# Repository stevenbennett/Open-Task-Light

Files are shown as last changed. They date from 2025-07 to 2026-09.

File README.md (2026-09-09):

# Open Task Light

An open-source desk lamp designed to be extended, repaired, and remade.

Open Task Light

> [!WARNING]
> **Before you start:** The Open Task Light is a challenging, hands-on project involving more than 20 printed parts, careful assembly, and thoughtful tuning. Think of your printer less like a magic part replicator and more like a tool to understand and occasionally wrangle. Expect to calibrate, inspect, and sometimes reprint parts to get the right fit and strength. If that kind of problem-solving sounds rewarding, you'll probably enjoy the build. You got this!

## Build an Open Task Light

Choose your build:

- **[Build from a hardware kit](https://opentasklight.com/products/open-task-light-hardware-kit)** — Start with all the hardware you need, print the required parts, and follow the assembly guide.
- **[Source the parts yourself](https://open-task-light.gitbook.io/open-task-light/self-sourcing-guide)** — Use the bills of materials and preparation guides to source, manufacture, and prepare your complete build.

**[Open the complete printing and assembly guide →](https://open-task-light.gitbook.io/open-task-light)**

## Repository contents

This repository contains the 3D models, electronics files, bills of materials, and manufacturing files used to build the Open Task Light.

## Project status

Planned additions include:

- Detailed assembly and preparation instructions for custom cables and processed parts such as the V-slot rails, turntable bearing, and QT Py.
- Drawings and schematics for professionally manufactured components, including sheet-metal parts and PCBs.

## Important design constraint

> **The horizontal arm is intentionally non-reversible.** This is a deliberate constraint related to the patent landscape surrounding this type of mechanism. Proposals to make the arm reversible will not be accepted into this project.

## More on the project

- [Sliding Into Perfection: The Open Task Light — Hackaday](https://hackaday.com/2026/09/01/sliding-into-perfection-the-open-task-light)
- [Building the Open Task Light — James Vaughan](https://jamesbvaughan.com/open-task-light)

## Community

- [Watch the project on YouTube](https://www.youtube.com/channel/UCvnxvXWYcOlmhRFvZ_ISP8g)
- [Join the Discord](https://discord.gg/B43ZVcBme4)
- [Support the project on Patreon](https://www.patreon.com/StevenBennett)

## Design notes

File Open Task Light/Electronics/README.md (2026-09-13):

# Open Task Light Electronics

Design source, bills of materials, and manufacturing files for the three custom PCBs used in the Open Task Light.

## Available files

- [Control Board](Control%20Board/) - Fusion source, Gerber and drill files, a component BOM, and pick-and-place exports for the main electronics PCB.
- [Power Link](Power%20Link/) - Fusion source, Gerber and drill files, a component BOM, and pick-and-place exports for the carriage power connection.
- [Power Track](Power%20Track/) - Fusion source, Gerber and drill files, and a component BOM for the rail power conductors.

For fabrication guidance and assembly instructions, see the [Custom Manufactured Parts section of the Open Task Light assembly guide](https://open-task-light.gitbook.io/open-task-light/self-sourcing-guide/custom-manufactured-parts). Check the guide before ordering boards or assembling the electronics.

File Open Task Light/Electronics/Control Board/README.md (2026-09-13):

# Control Board PCB

The Control Board is the primary electronics PCB for the Open Task Light.

For fabrication details, required parts, and assembly instructions, see the [Control Board section of the Open Task Light assembly guide](https://open-task-light.gitbook.io/open-task-light/self-sourcing-guide/custom-manufactured-parts/control-board).

## Files

- `control-board-gerbers.zip` contains the Gerber, solder-mask, solder-paste, silkscreen, board-profile, and drill files required to order the bare PCB.
- `Source/Control Board.brd` and `Source/Control Board.sch` are the editable Autodesk Fusion Electronics source files.
- `Assembly/control-board-bom.csv` is the Fusion Electronics BOM for the components installed on the PCB.
- `Assembly/PnP_Control Board_front.csv` and `Assembly/PnP_Control Board_back.csv` are the front- and back-side pick-and-place exports from Fusion Electronics.

## Manufacturing notes

Upload the Gerber ZIP when ordering the bare PCB. If using an assembly service, you may need to reformat the BOM and placement files to meet the manufacturer's requirements.

The Adafruit QT Py ESP32-S2 is sourced separately and plugs into the headers after the Control Board is assembled. Confirm the board outline, holes, component positions, board sides, rotations, and component polarity in the manufacturer's preview before ordering.

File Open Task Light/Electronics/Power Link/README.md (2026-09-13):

# Power Link PCB

The Power Link is the two-conductor PCB that transfers power between the vertical and horizontal Power Tracks through the carriage.

For fabrication details, required parts, and assembly instructions, see the [Power Link section of the Open Task Light assembly guide](https://open-task-light.gitbook.io/open-task-light/self-sourcing-guide/custom-manufactured-parts/power-link).

## Files

- `power-link-gerbers.zip` contains the Gerber, solder-mask, solder-paste, board-profile, and drill files required to order the bare PCB.
- `Source/Power Link.brd` and `Source/Power Link.sch` are the editable Autodesk Fusion Electronics source files.
- `Assembly/power-link-bom.csv` is the Fusion Electronics BOM for the eight Mill-Max OmniBall spring-loaded contacts.
- `Assembly/PnP_Power Link_front.csv` and `Assembly/PnP_Power Link_back.csv` are the front- and back-side pick-and-place exports from Fusion Electronics.

## Manufacturing notes

Upload the Gerber ZIP when ordering the bare PCB. If using an assembly service, you may need to reformat the BOM and placement files to meet the manufacturer's requirements.

The OmniBall contacts are individual surface-mount parts and are best installed using a reflow process or professional assembly service. Confirm the board outline, holes, component positions, board sides, and rotations in the manufacturer's preview before ordering.

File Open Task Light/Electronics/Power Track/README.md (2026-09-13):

# Power Track PCB

The Power Track is the long, two-conductor PCB that carries 24 V along the Open Task Light rails.

For fabrication details, required parts, and assembly instructions, see the [Power Track section of the Open Task Light assembly guide](https://open-task-light.gitbook.io/open-task-light/self-sourcing-guide/custom-manufactured-parts/power-track).

## Files

- `power-track-gerbers.zip` contains the fabrication and drill files required to order the bare PCB.
- `Source/Power Track.brd` and `Source/Power Track.sch` are the editable Autodesk Fusion Electronics source files.
- `Assembly/power-track-bom.csv` is the Fusion Electronics BOM for the two parts installed on the PCB.
- Pick-and-place files are not included because the Power Track is intended to be assembled by hand.

## Manufacturing notes

Upload the Gerber ZIP when ordering the bare PCB. Assemble the surface-mount standoff and right-angle Micro-Lock connector by hand as described in the assembly guide.

Confirm the board outline, plated and non-plated holes, and exposed contact areas in the manufacturer's preview before ordering.

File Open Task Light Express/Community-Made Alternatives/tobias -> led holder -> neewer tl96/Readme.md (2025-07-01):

added files to use the neewer tl96 rgb light stick.
space for two 8x3 mm magnets
also created a grid which should direct the light more straigt, but i dont use it as it darkens everything to much, but maybe someone likes it :)
as the light is not the lightes one i also used a bit of felt to increase friction





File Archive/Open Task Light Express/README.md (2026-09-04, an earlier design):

# Open Task Light Express

> [!IMPORTANT]
> Open Task Light Express is an archived community project based on an earlier version of the Open Task Light. It's preserved for reference and to retain the work and contributions of its original contributors, but it isn't actively maintained and isn't compatible with the current Open Task Light design, parts, or assembly instructions. This variant of the project was a way to use a battery powered LED on the end of the horizontal arm as a quick and affordable way to build an Open Task Light-style lamp.

The Open Task Light Express is the more approachable, completely customizable variant of the Open Task Light project. The Express is constructed from a simplified parts list which includes an out-of-the-box lighting and electronics solution. Check out the project video for a full overview: [https://www.youtube.com/watch?v=xv9rY6r6liI](https://www.youtube.com/watch?v=xv9rY6r6liI)

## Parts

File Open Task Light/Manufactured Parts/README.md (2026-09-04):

# Manufactured Parts

Design files for the custom metal parts used in the Open Task Light.

- [Aluminum Heat Pipe Top Plate](Aluminum%20Heat%20Pipe%20Top%20Plate/)
- [Copper LED Bracket](Copper%20LED%20Bracket/)

For material and fabrication guidance, see the [Custom Manufactured Parts section](https://open-task-light.gitbook.io/open-task-light/self-sourcing-guide/custom-manufactured-parts) of the Open Task Light GitBook before ordering these parts.

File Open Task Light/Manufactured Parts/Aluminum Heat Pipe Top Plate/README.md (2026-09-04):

# Aluminum Heat Pipe Top Plate

This directory contains the DXF for manufacturing the aluminum heat pipe top plate.

The part is intended to be laser cut. Services such as [SendCutSend](https://sendcutsend.com/) and [OSH Cut](https://oshcut.com/) can quote the part directly from the DXF.

> **Secondary operation required:** Tap the two smaller holes M3 x 0.5 after cutting. This can be done by the cutting service or by hand. The DXF contains the pilot-hole geometry, not finished threaded holes.

- [Download the DXF](aluminum-heat-pipe-top-plate.dxf)
- [View manufacturing guidance in GitBook](https://open-task-light.gitbook.io/open-task-light/self-sourcing-guide/custom-manufactured-parts/aluminum-heat-pipe-top-plate)

Review the material, thickness, secondary operations, and other specifications in GitBook before ordering the part. The DXF alone does not define the complete finished part.

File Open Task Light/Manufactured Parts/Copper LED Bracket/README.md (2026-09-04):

# Copper LED Bracket

This directory contains the DXF for manufacturing the copper LED bracket.

The part is intended to be laser cut from C110 copper. Services such as [SendCutSend](https://sendcutsend.com/) and [OSH Cut](https://oshcut.com/) can quote the part directly from the DXF.

- [Download the DXF](copper-led-bracket.dxf)
- [View manufacturing guidance in GitBook](https://open-task-light.gitbook.io/open-task-light/self-sourcing-guide/custom-manufactured-parts/copper-led-bracket)

Review the material, thickness, forming, and other specifications in GitBook before ordering the part. The DXF alone does not define the complete finished part.

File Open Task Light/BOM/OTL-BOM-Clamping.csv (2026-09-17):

Item | Category | Quantity | Unit | Description | Variant Attribute | Options | Purchase Options | Approved Alternatives | Source Critical | Criticality Note | Build Applicability | Requires Processing | Processing Note | Manufacturer
1.5 mm Heat-Shrink Tubing | Consumables | 50 | mm | 1.5 mm nominal-diameter heat-shrink tubing. Cut to 50 mm. |  | 1.5 mm Heat-Shrink Tubing | Amazon: https://amzn.to/4gCbjuF |  | No |  | Clamping | No
1.75 mm TPU Filament | Consumables | 50 | mm | A strand of TPU filament used as a flexible strain relief. Cut to 50 mm. |  | 1.75 mm TPU Filament | Amazon: https://amzn.to/4d789Om |  | No |  | Clamping | No
1/2-Inch Steel Spacer | Mechanical | 1 | each | Zinc-Plated Steel Unthreaded Spacer 1/2" OD, 1-3/8" Long, for Number 10 Screw Size |  | Steel Spacer | McMaster-Carr: https://www.mcmaster.com/92414A444/ |  | Yes | This steel spacer (McMaster-Carr 92414A444) and the bronze sleeve bearing (bushing, McMaster-Carr 6391K739) used in the clamping base were selected from dozens of combinations because they fit together snugly without wobble. Use the specified pair; any substitute must be checked with its mating part to confirm the same snug, wobble-free fit. | Clamping | No |  | McMaster Carr Source
2-Inch C-Clamp | Mechanical | 1 | each |  |  | 2-Inch C-Clamp | Home Depot: https://www.homedepot.com/p/Husky-2-in-C-Clamp-HD-2016-0302/207119522 |  | No |  | Clamping | No |  | Husky
2020 V-Slot Rail - 500 mm | Mechanical | 2 | each | 2020 V-Slot Linear Rail | Rail Color | Black | Silver | Black - Bulkman3D: https://bulkman3d.com/product/v-slot-2020/?attribute_color=Black+anodised&attribute_length=2020-500mm | Silver - Bulkman3D: https://bulkman3d.com/product/v-slot-2020/?attribute_color=Silver+anodised&attribute_length=2020-500mm | Alternate Black - Maker Store: https://makerstore.cc/product/black-v-slot-20-x-20mm/ | Alternate Silver - Maker Store: https://makerstore.cc/product/v-slot-20-x-20mm/ |  | No |  | Clamping | Freestanding | Yes | M5 tap all rail ends (16 mm minimum for clamping base hole. All others can be 10 mm+) Optionally sand horizontal rail interior before gluing the heat pipe. | Bulkman3D
3 mm Heat-Shrink Tubing | Consumables | 70 | mm | 3 mm nominal-diameter heat-shrink tubing. Cut to 70 mm. |  | 3 mm Heat-Shrink Tubing | Amazon: https://amzn.to/45YNYhQ |  | No |  | Clamping | No
4.8 mm Adhesive-Lined Heat-Shrink Tubing | Consumables | 44 | mm | 4.8 mm nominal-diameter heat-shrink tubing. Cut to 44 mm. |  | 4.8 mm Adhesive-Lined Heat-Shrink Tubing | Amazon: https://amzn.to/4xxhuaK |  | No |  | Clamping | No
5.5 mm Steel Ball | Mechanical | 1 | each | Wear-Resistant alloy steel ball used in the clamping base |  | 5.5 mm Steel Ball | McMaster-Carr: https://www.mcmaster.com/9292K74/ |  | No |  | Clamping | No
AC Power Cord (US) | Electronics | 1 | each | 6' (1.83m) Power Cord Black NEMA 1-15P To IEC 320-C7 SPT-2 |  | AC Power Cord | DigiKey: https://www.digikey.com/en/products/detail/same-sky-formerly-cui-devices/AC-C7-NA/2743487 |  | No |  | Clamping | Freestanding | No |  | Same Sky
AC/DC Power Supply | Electronics | 1 | each | 24V 36 W AC/DC External Desktop (Class II) Adapter Cord |  | AC/DC Power Supply | DigiKey: https://www.digikey.com/en/products/detail/tt-electronics-power-partners-inc/PSAD36BSF-14-B2/15838735 |  | No |  | Clamping | Freestanding | No |  | TT Electronics/Power Partners Inc.
Adafruit QT Py ESP32 S2 | Electronics | 1 | each | Adafruit QT Py ESP32-S2 WiFi Dev Board |  | Adafruit QT Py ESP32 S2 | Adafruit: https://www.adafruit.com/product/5325 | Alternate DigiKey: https://www.digikey.com/en/products/detail/adafruit-industries-llc/5325/15901779 |  | No |  | Clamping | Freestanding | Yes | Flash software, solder and trim headers to ~4.6 mm (without header insulator) | Adafruit
Alcohol Wipe | Consumables | 4 | each | 70% isopropyl alcohol prep pad used to clean parts before assembly. |  | Alcohol Wipe | Amazon: https://amzn.to/4xwmNXG |  | No |  | Clamping | Freestanding | No
Aluminum Heat Pipe Top Plate | Lighting | 1 | each | Laser cut 6061 T6 Aluminum (.063" thick) with two tapped holes (m3x0.5) |  | Aluminum Heat Pipe Top Plate | Open Task Light Shop: https://opentasklight.com/products/led-bracket-set | Alternate Manufacturing guide: https://open-task-light.gitbook.io/open-task-light/self-sourcing-guide/custom-manufactured-parts/aluminum-heat-pipe-top-plate |  | No |  | Clamping | Freestanding | No
Bronze Sleeve Bearing | Mechanical | 1 | each | Oil-Embedded 841 Bronze Sleeve Bearing, 1/2” shaft, 11/16” housing, 7/8” length |  | Bronze Sleeve Bearing | McMaster-Carr: https://www.mcmaster.com/6391K739/ |  | Yes | This bronze sleeve bearing (bushing, McMaster-Carr 6391K739) and the steel spacer (McMaster-Carr 92414A444) used in the clamping base were selected from dozens of combinations because they fit together snugly without wobble. Use the specified pair; any substitute must be checked with its mating part to confirm the same snug, wobble-free fit. | Clamping | No |  | McMaster Carr Source
Carriage Wheel | Mechanical | 6 | each |  | Wheel Color | Black | Clear | Black - Open Task Light Shop: https://opentasklight.com/products/wheelset | Clear - Open Task Light Shop: https://opentasklight.com/products/wheelset | Alternate Black - Bulkman3D: https://bulkman3d.com/product/vk0001/ | Alternate Black - Maker Store: https://makerstore.cc/product/solid-v-wheel-kit/ | Alternate Clear - Bulkman3D: https://bulkman3d.com/product/vk0012/?attribute_bearings=625-2RS+Bearings | Alternate Clear - Maker Store: https://makerstore.cc/product/solid-v-xtreme-wheel-kit/ |  | No |  | Clamping | Freestanding | No |  | Bulkman3D
Control Board | Electronics | 1 | each | Assembled control PCB for the Open Task Light. Purchase an assembled board or use the published manufacturing files to have one produced. |  | Control Board | Open Task Light Shop: https://opentasklight.com/products/otl-control-board | Alternate Manufacturing guide: https://open-task-light.gitbook.io/open-task-light/self-sourcing-guide/custom-manufactured-parts/control-board |  | No |  | Clamping | Freestanding | No
Copper LED Bracket | Lighting | 1 | each | Laser cut copper (.063" thick) with 90 degree bend |  | Copper LED Bracket | Open Task Light Shop: https://opentasklight.com/products/led-bracket-set | Alternate Manufacturing guide: https://open-task-light.gitbook.io/open-task-light/self-sourcing-guide/custom-manufactured-parts/copper-led-bracket |  | No |  | Clamping | Freestanding | No
Counterweight Flex Tab Spring | Mechanical | 2 | each | 6.350 mm x 4.369 mm Music Wire Compression Spring |  | Counterweight Flex Tab Spring | The Spring Store: https://www.thespringstore.com/pc018-172-4500-mw-0250-c-n-in.html?um=me |  | No |  | Clamping | Freestanding | No |  | The Spring Store by Acxess Spring
Flat Copper Heat Pipe - 350 mm | Lighting | 1 | each | Flat sintered copper heat pipe measuring 350 × 8.13 × 2.8 mm. Transfers heat from the LED assembly along the horizontal rail. A 400 mm version also works. |  | Flat Copper Heat Pipe - 350 mm | DigiKey: https://www.digikey.com/en/products/detail/advanced-thermal-solutions-inc/ATS-HP-F6L350S12W-273/7899666 |  | Yes | Heat pipes contain an internal wick structure and working fluid, so products with the same external dimensions should not be assumed to equal. I tried a lower-cost overseas source, but the heat pipes arrived bent; other buyers reported the same problem, and I did not verify their thermal performance. Use the recommended part, or verify a substitute’s dimensions and thermal capacity before use. | Clamping | Freestanding | No |  | Advanced Thermal Solutions Inc.
GT2 Idler Pulley | Mechanical | 1 | each | Low profile GT2 toothless idler pulley |  | GT2 Idler Pulley | AliExpress: https://www.aliexpress.us/item/3256804188092382.html |  | Yes | M5 bore, low profile flange. | Clamping | Freestanding | No |  | Guangzhou magnesium Lun Electronic Technology Co. LTD
GT2 Timing Belt - 5 mm Wide | Mechanical | 390 | mm | Open-ended GT2 timing belt with 2 mm pitch and 5 mm width. One lamp requires a 390 mm cut length. |  | GT2 Timing Belt - 5 mm Wide | Bulkman3D: https://bulkman3d.com/product/gt000-gt0003/?attribute_belt-pitch=GT2-Pitch+2mm&attribute_belt-width=5mm | Alternate Maker Store: https://makerstore.cc/product/gt2-2mm-timing-belt-per-meter/ |  | No |  | Clamping | Freestanding | Yes | Cut to a finished length of 390 mm.
LED | Lighting | 1 | each |  | LED Temperature | 3000K | 4000K | 3000K - Open Task Light Shop: https://opentasklight.com/products/led-chip?variant=51751642530088 | 4000K - Open Task Light Shop: https://opentasklight.com/products/led-chip?variant=51751642562856 | Alternate 3000K - Mouser: https://www.mouser.com/ProductDetail/941-CXB15120PF0ZAL7C | Alternate 3000K - Mouser: https://www.mouser.com/en/ProductDetail/Cree-LED/CXB1512-0000-00PF0Z0A30H?qs=IPgv5n7u5QYZ%252Bp8lzbtijg%3D%3D | Alternate 4000K - Mouser: https://www.mouser.com/ProductDetail/Cree-LED/CXB1512-0000-00PF0Z0A40H?qs=IPgv5n7u5Qaus3Sf%252BbYVcg%3D%3D | 3000K: Cree CXB1512-0000-00PF0Z0A30H is an approved 3000K, 95 CRI replacement with the same package and electrical requirements. | No |  | Clamping | Freestanding | No |  | Cree LED
LED Socket | Lighting | 1 | each | LED socket for 15.8 x 15.8 mm COB LED packages. |  | LED Socket | Mouser: https://www.mouser.com/ProductDetail/Ledil/F19861_HEKLA-G2B-TW1?qs=iLKYxzqNS74Cxis7PG1dhw%3D%3D |  | No |  | Clamping | Freestanding | No |  | Ledil
Lens | Lighting | 1 | each | Wide-beam LED lens with Holder C and a 55-degree beam angle. |  | Lens | Mouser: https://www.mouser.com/ProductDetail/Ledil/CP16109_CARMEN-50-W-C?qs=0lQeLiL1qyZMDUJ1jrzybw%3D%3D |  | No |  | Clamping | Freestanding | No |  | Ledil
M2 Square Nut | Fasteners | 2 | each | 18-8 Stainless Steel Thin-Profile Square Nuts |  | M2 Square Nut | McMaster-Carr: https://www.mcmaster.com/97258A121/ |  | No |  | Clamping | Freestanding | No |  | McMaster Carr Source
M2 x 6 mm Flat Head Screw | Fasteners | 8 | each | Black-oxide alloy steel hex-drive flat head screw with M2 x 0.4 mm thread and a 90-degree countersink. |  | M2 x 6 mm Flat Head Screw | McMaster-Carr: https://www.mcmaster.com/91294A004/ |  | No |  | Clamping | Freestanding | No |  | McMaster Carr Source
M3 SMD Standoff | Electronics | 2 | each | Steel M3 surface-mount standoff, 2.5 mm high, installed on the Power Track PCB. |  | M3 SMD Standoff | DigiKey: https://www.digikey.com/en/products/detail/w%C3%BCrth-elektronik/78614025360/15792300 |  | No |  | Clamping | Freestanding | No |  | Würth Elektronik
M3 Square Nut | Fasteners | 1 | each | 18-8 Stainless Steel Thin-Profile Square Nuts M3 x 0.5 mm Thread |  | M3 Square Nut | McMaster-Carr: https://www.mcmaster.com/97258A101/ |  | No |  | Clamping | Freestanding | No
M3 x 10 mm Socket Head Screw | Fasteners | 5 | each | 18-8 Stainless Steel Socket Head Screw M3 x 0.5 mm Thread Size, 10 mm Long, Fully Threaded |  | M3 x 10 mm Socket Head Screw | McMaster-Carr: https://www.mcmaster.com/91292A113/ |  | No |  | Clamping | Freestanding | No |  | McMaster Carr Source
M3 x 4 mm Set Screw | Fasteners | 2 | each | Alloy Steel Flat-Tip Set Screw, M3 x 0.5 mm Thread, 4 mm Long |  | M3 x 4 mm Set Screw | McMaster-Carr: https://www.mcmaster.com/93245A098/ |  | No |  | Clamping | Freestanding | No
M5 Aluminum Spacer - 3 mm | Mechanical | 3 | each | M5x3 mm, 10 mm OD Round Aluminum Spacer |  | M5 Aluminum Spacer - 3 mm | Bulkman3D: https://bulkman3d.com/product/round-spacers-m3-m4-m5-m6-m8/ | Alternate Maker Store: https://makerstore.cc/product/metric-aluminum-spacers/ |  | No |  | Clamping | Freestanding | No
M5 Aluminum Spacer - 6 mm | Mechanical | 5 | each | M5x6 mm, 10 mm OD Round Aluminum Spacer |  | M5 Aluminum Spacer - 6 mm | Bulkman3D: https://bulkman3d.com/product/round-spacers-m3-m4-m5-m6-m8/ | Alternate Maker Store: https://makerstore.cc/product/metric-aluminum-spacers/ |  | No |  | Clamping | Freestanding | No
M5 Eccentric Spacer | Mechanical | 2 | each | Stainless Steel 8HEX*6 Eccentric Spacer |  | M5 Eccentric Spacer | Bulkman3D: https://bulkman3d.com/product/hd0004-hd0005/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 | Alternate Maker Store: https://makerstore.cc/product/eccentric-spacers-8mm-hex/ |  | No |  | Clamping | Freestanding | No |  | Bulkman3D
M5 Nylon Nut | Fasteners | 7 | each | M5x4.5 mm Low Profile Aluminum Flange Nylon Nut (clockwise) |  | M5 Nylon Nut | AliExpress: https://www.aliexpress.us/item/2251832652739547.html?mp=1 |  | No |  | Clamping | Freestanding | No |  | Custom
M5 Spring-Loaded Tee Nut | Fasteners | 5 | each | 20-M5 Stainless Steel spring loaded tee nut |  | M5 Spring-Loaded Tee Nut | Bulkman3D: https://bulkman3d.com/product/hd0010-30/ | Alternate Maker Store: https://makerstore.cc/product/spring-loaded-tee-nuts/ |  | No |  | Clamping | Freestanding | No |  | Bulkman3D
M5 Square Nut | Fasteners | 1 | each | 18-8 Stainless Steel Square Nuts M5 x 0.8 mm Thread |  | M5 Square Nut | McMaster-Carr: https://www.mcmaster.com/90225A101/ |  | No |  | Clamping | Freestanding | No |  | McMaster Carr Source
M5 x 10 mm Low-Profile Screw | Fasteners | 1 | each | M5x10 mm Low Profile Screw |  | M5 x 10 mm Low-Profile Screw | Bulkman3D: https://bulkman3d.com/product/hd002/ | Alternate Maker Store: https://makerstore.cc/product/m5-low-profile-screws/ |  | No |  | Freestanding | No
M5 x 12 mm Low-Profile Screw | Fasteners | 2 | each | M5x12 mm Low Profile Screw |  | M5 x 12 mm Low-Profile Screw | Bulkman3D: https://bulkman3d.com/product/hd002/ | Alternate Maker Store: https://makerstore.cc/product/m5-low-profile-screws/ |  | No |  | Clamping | Freestanding | No
M5 x 15 mm Low-Profile Screw | Fasteners | 2 | each | M5x15 mm Low Profile Screw |  | M5 x 15 mm Low-Profile Screw | Bulkman3D: https://bulkman3d.com/product/hd002/ | Alternate Maker Store: https://makerstore.cc/product/m5-low-profile-screws/ |  | No |  | Clamping | Freestanding | No
M5 x 27 mm Low-Profile Screw | Fasteners | 7 | each | M5x27 mm Low Profile Screw |  | M5 x 27 mm Low-Profile Screw | Bulkman3D: https://bulkman3d.com/product/hd002/ | Alternate Maker Store: https://makerstore.cc/product/m5-low-profile-screws/ |  | No |  | Clamping | Freestanding | No
M5 x 50 mm Low-Profile Socket Head Screw | Fasteners | 1 | each | Alloy Steel Low-Profile Socket Head Screw Hex Drive, M5 x 0.8 mm Thread, 50 mm Long |  | M5 x 50 mm Low-Profile Socket Head Screw | McMaster-Carr: https://www.mcmaster.com/93070A158/ |  | Yes | Screw socket must be centered in screw head (some lower cost screws don't have this) | Clamping | No
M5 x 8 mm Low-Profile Screw | Fasteners | 7 | each | M5x8 mm Low Profile Screw |  | M5 x 8 mm Low-Profile Screw | Bulkman3D: https://bulkman3d.com/product/hd002/ | Alternate Maker Store: https://makerstore.cc/product/m5-low-profile-screws/ |  | No |  | Clamping | Freestanding | No
M5 x 8 mm Narrow-Head Socket Cap Screw | Fasteners | 1 | each | M5x8x6.6 Nonstandard Small Head Stainless Steel Socket Cap Screw |  | M5 x 8 mm Narrow-Head Socket Cap Screw | AliExpress: https://www.aliexpress.us/item/3256809045102684.html?mp=1 | Alternate McMaster-Carr: https://www.mcmaster.com/97710A127/ |  | No |  | Clamping | Freestanding | No
Micro-Lock Connector - Right Angle | Electronics | 2 | each | Connector Header Through Hole, Right Angle 2 position 0.049" (1.25 mm) |  | Micro-Lock Connector - Right Angle | DigiKey: https://www.digikey.com/en/products/detail/molex/2200980271/22111645 |  | No |  | Clamping | Freestanding | No |  | Molex
Molex Micro-Lock Cable - 100 mm | Electronics | 1 | each | Two-position socket-to-socket cable assembly (unmodified), used between the control board and horizontal power track. |  | Molex Micro-Lock Cable - 100 mm | DigiKey: https://www.digikey.com/en/products/detail/molex/0451110201/7915875 |  | No |  | Clamping | Freestanding | No |  | Molex
Molex Micro-Lock Cable - 150 mm | Electronics | 1 | each | Two-position socket-to-socket cable assembly used as stock for the 75 mm LED cable and freestanding base power cable. |  | Molex Micro-Lock Cable - 150 mm | DigiKey: https://www.digikey.com/en/products/detail/molex/0451110202/7915876 |  | No |  | Clamping | Freestanding | No |  | Molex
Molex Micro-Lock Cable - 450 mm | Electronics | 1 | each | Two-position socket-to-socket cable assembly used as stock for the clamping base power cable. |  | Molex Micro-Lock Cable - 450 mm | DigiKey: https://www.digikey.com/en/products/detail/molex/0451110205/7915878 |  | No |  | Clamping | No |  | Molex
Power Link | Electronics | 1 | each | Power transfer board |  | Power Link | Open Task Light Shop: https://opentasklight.com/products/replacement-power-link | Alternate Manufacturing guide: https://open-task-light.gitbook.io/open-task-light/self-sourcing-guide/custom-manufactured-parts/power-link |  | No |  | Clamping | Freestanding | Yes
Power Track PCB | Electronics | 2 | each | Power transmission track |  | Power Track PCB | Open Task Light Shop: https://opentasklight.com/products/otl-power-tracks-pair | Alternate Manufacturing guide: https://open-task-light.gitbook.io/open-task-light/self-sourcing-guide/custom-manufactured-parts/power-track |  | No |  | Clamping | Freestanding | No
Straight DC Power Jack | Electronics | 1 | each | Straight solder-type DC barrel jack, 5.5 mm OD × 2.5 mm ID. Same Sky PR-002B. |  | Straight DC Power Jack | DigiKey: https://www.digikey.com/en/products/detail/same-sky-formerly-cui-devices/PR-002B/724804 |  | No |  | Clamping | No |  | Same Sky
Thermal Epoxy | Consumables | 1 | each | Two-part thermal epoxy used to bond the heat pipe to the horizontal rail. Wakefield BT-301-50M cures black and is recommended for black rails, but works with either rail color and is the less expensive option. MG Chemicals 8329TFF-50ML cures translucent and works with either rail color, but costs more. A compatible dual-cartridge dispensing gun is required. |  | Thermal Epoxy | DigiKey: https://www.digikey.com/en/products/detail/wakefield-thermal-solutions/BT-301-50M/7317821 |  | No |  | Clamping | Freestanding | No |  | Wakefield Thermal Solutions
Thermal Paste | Lighting | 2 | each | GD900 Thermal Grease 0.5g 4.8W/mk |  | Thermal Paste | Amazon: https://amzn.to/4ygiMa4 | Alternate AliExpress: https://www.aliexpress.us/item/3256807889217363.html?sourceType=1 |  | No |  | Clamping | Freestanding | No
Weight Material | Weight Material | 550 | gram | S550 steel shot. Weight material for freestanding base and counterweight. |  | Weight Material | Amazon: https://www.amazon.com/dp/B01M0NKLY6?ref_=ppx_hzsearch_conn_dt_b_fed_asin_title_2&th=1 |  | No |  | Clamping | Freestanding | No |  | N/A

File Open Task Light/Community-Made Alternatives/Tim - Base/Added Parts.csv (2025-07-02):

Part Name | Quantity | Category | Link | European supplier | Note | Unit Cost (USD) | Total Cost (USD)
2-Wire Slipring | 1 | Hardware | https://www.amazon.com/dp/B09VKY42R4/ref=sr_1_8?keywords=electrical+slip+ring&qid=1676837754&sr=8-8 | https://www.amazon.de/dp/B01CJJNL46?psc=1&ref=ppx_yo2ov_dt_b_product_details | Used in the Base | $11.13 | $11.13
6004-2RS Bearing (Pack of 2) | 1 | Hardware | https://www.amazon.com/dp/B08DN95C11?__mk_de_DE=%C3%85M%C3%85%C5%BD%C3%95%C3%91 | https://www.amazon.de/dp/B0971WTC8Y?psc=1&ref=ppx_yo2ov_dt_b_product_details | Used in the Base | $17.50 | $17.50

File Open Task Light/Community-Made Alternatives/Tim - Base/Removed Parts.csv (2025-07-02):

Part Name | Quantity | Category | Link | European supplier | Note | Unit Cost (USD) | Total Cost (USD)
C-Clamp | 1 | Structure/Motion | https://amzn.to/3c4k5Et |  | Any small c-clamp will work | $15.10 | $15.10
M5 Nyloc Nuts (Pack of 50) | 1 | Hardware | https://amzn.to/3T3DINM | https://nl.aliexpress.com/item/33030388407.html?mp=1 | Used in base | $6.49 | $6.49

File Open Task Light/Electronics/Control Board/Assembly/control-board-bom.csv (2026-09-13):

Qty | Value | Device | Package | Parts | Description | DATASHEET | MANUFACTURER | MPN
1 | 2200970271 | 2200970271CONN_2200970000-SD_02_MOL | CONN_2200970000-SD_02_MOL | MICROLOCK-VERTICAL | 1.25WB MLP SGL VT TH ASSY 2CKT B | https://www.molex.com/content/dam/molex/molex-dot-com/products/automated/en-us/salesdrawingpdf/220/220097/2200970271_sd.pdf | Molex | 2200970271
1 | 2200980271 | 220098-0271 | 2200980271 | MICROLOCK-RIGHT-ANGLE | 1.25WB MLP SGL RA TH ASSY 2CKT B | https://www.molex.com/en-us/products/part-detail-pdf/2200980271?display=pdf | Molex | 2200980271
3 | 807-22-001-10-001101 | 807-22-001-10-001101CONN_807-22-001-10-001101_MIM | CONN_807-22-001-10-001101_MIM | +BTN, -BTN, POWERBTN | CONTACT SPRING LOADED T/H GOLD | https://www.mill-max.com/sites/default/files/external/catalog/2018-07/004-022.pdf | Mill-Max | 807-22-001-10-001101
2 | CES-107-01-G-S | SAMTEC-CES-107-01-X-SJ | SAMTEC-CES-107-01-X-S | HEADER1, HEADER2 | CONN RCPT 7POS 0.1 GOLD PCB | https://suddendocs.samtec.com/catalog_english/ces.pdf | Samtec | CES-107-01-G-S
3 | CL31B104KBCNNNC | CL31B104KBCNNNC | CAPC3216X100N | 0.1UCAP[1/3], 0.1UCAP[2/3], 0.1UCAP[3/3] | CAP CER 0.1UF 50V X7R 1206 | https://product.samsungsem.com/mlcc/CL31B104KBCNNN.do | Samsung Electro-Mechanics | CL31B104KBCNNNC
2 | EEE-FTH101XAP | EEEFTH101XAP | CAP_EEEFTH101XAP | 100UF_CAP[1/2], 100UF_CAP[2/2] | CAP ALUM 100UF 20% 50V SMD | https://industrial.panasonic.com/cdbs/www-data/pdf/RDE0000/RDE0000C1269.pdf | Panasonic | EEE-FTH101XAP
2 | PMEG4010EGWX | PMEG4010EGWX | SOD-123 | D1, D3 | DIODE SCHOTTKY 40V 1A SOD123 | https://assets.nexperia.com/documents/data-sheet/PMEG4010EGW.pdf | Nexperia | PMEG4010EGWX
1 | R-78K5.0-1.0 | R-78K5.0-1.0SIP3_R-78K-0.5_RCP | R-78K5.0-1.0_RCP | RECOM-BUCK | 1A DC/DC-CONVERTER 'INNOLINE' SI | https://recom-power.com/pdf/Innoline/R-78K-1.0.pdf | RECOM Power | R-78K5.0-1.0
3 | RC1206JR-075K6L | RC1206JR-075K6L | RESC3116X65N | RES5.6K1, RES5.6K2, RES5.6K3 | RES 5.6K OHM 5% 1/4W 1206 | https://media.digikey.com/pdf/Data%20Sheets/Yageo%20PDFs/RC_Series_L_Suffix_Rev12_DS.pdf | YAGEO | RC1206JR-075K6L
1 | RCD-24-0.70/VREF | RCD-24-0.70_VREF | RCD24030 | RECOM-DRIVER | LED DRIVER CC BUCK 2-35V 700MA | https://recom-power.com/pdf/Lightline_DC-DC/RCD-24.pdf | RECOM Power | RCD-24-0.70/VREF
1 | SMD2016B100TF/33 | SMD2016B100TF/33 | SMD2016B100TF/33 | FUSE | PTC RESET FUSE 33V 1.1A 2016 | https://yageogroup.com/component-documentation/download/datasheet/SMD2016B100TF%2F33?lang=en | YAGEO | SMD2016B100TF/33
1 | SMF4L24AT1G | SMF4L24AT1G | SODFL3619X98N | TVS | TVS DIODE 24VWM 38.9VC SOD123F | https://www.littelfuse.com/assetdocs/littelfuse_tvs_diode_smf4l_datasheet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 | Littelfuse | SMF4L24AT1G
1 | TMP75AQDRQ1 | TMP75AQDRQ1D8_TEX | D8_TEX | TMP75 | SENSOR DIGITAL -40C-125C 8SOIC | https://www.ti.com/lit/ds/symlink/tmp75-q1.pdf | Texas Instruments | TMP75AQDRQ1
1 | TS12A4515D | TS12A4515DD8-L | D8-L | U1 | IC SWITCH SPST-NCX1 10OHM 8SOIC | https://www.ti.com/lit/ds/symlink/ts12a4515.pdf | Texas Instruments | TS12A4515D
1 | VEML7700-TR | VEML7700-TR | XDCR_VEML7700-TR | VEML7700 | SENSOR OPT 545NM AMBIENT 4SMD | https://www.vishay.com/docs/84286/veml7700.pdf | Vishay | VEML7700-TR

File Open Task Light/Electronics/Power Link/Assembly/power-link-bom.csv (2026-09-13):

Qty | Value | Device | Package | Parts | Description | DATASHEET | MANUFACTURER | MPN
8 | 0945-0-15-20-09-14-11-0 | 0945-0-15-20-09-14-11-0 | MILL_MAX_0945_SMD | PIN1, PIN2, PIN3, PIN4, PIN5, PIN6, PIN7, PIN8 | Surface Mount Spring-Loaded Pin | https://www.mill-max.com/assets/pdfs/0945.pdf | Mill-Max | 0945-0-15-20-09-14-11-0

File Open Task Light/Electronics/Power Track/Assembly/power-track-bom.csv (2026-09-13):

Qty | Value | Device | Package | Parts | Description | DATASHEET | MANUFACTURER | MPN
1 | 2200980271 | 220098-0271 | 2200980271 | J1 | 1.25WB MLP SGL RA TH ASSY 2CKT B | https://www.molex.com/en-us/products/part-detail-pdf/2200980271?display=pdf | Molex | 2200980271
1 | 78614025360 | WE-SMSA_3.3MMDEFAULT | WE-SMSA_78614020360 | MP1 | Round Spacer Threaded M3 Steel 0.098in (2.50mm) | https://www.we-online.com/components/products/datasheet/78614025360.pdf | Würth Elektronik | 78614025360

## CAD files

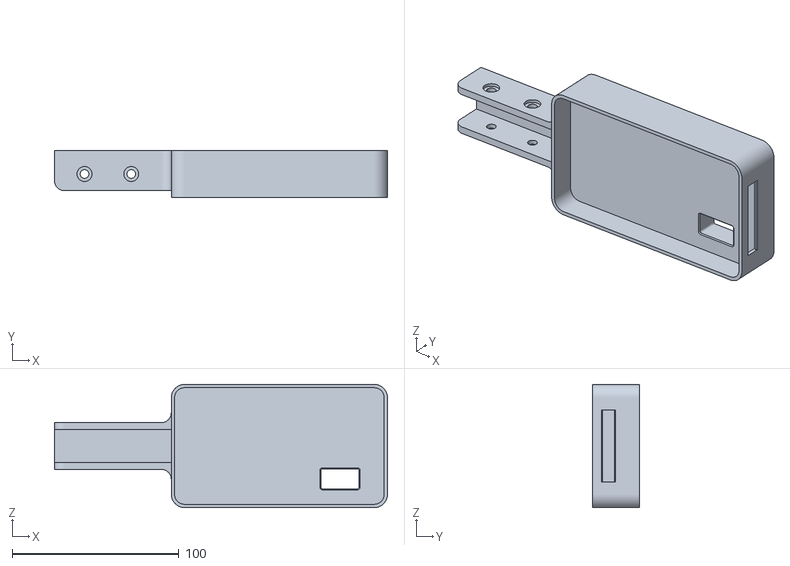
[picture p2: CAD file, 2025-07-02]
Open Task Light Express/Community-Made Alternatives/brukhabtu - LED Holder (LumeCube)/Lume Cube Bicolor Panel.stl
199.6 x 28.0 x 73.9

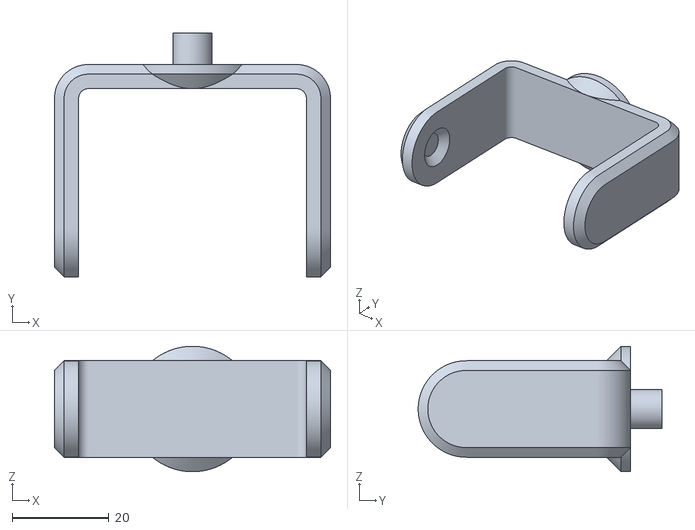
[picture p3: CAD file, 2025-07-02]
Open Task Light Express/Community-Made Alternatives/jfuchs - Gimbal/Outer ring.stl
57.2 x 50.5 x 26.0

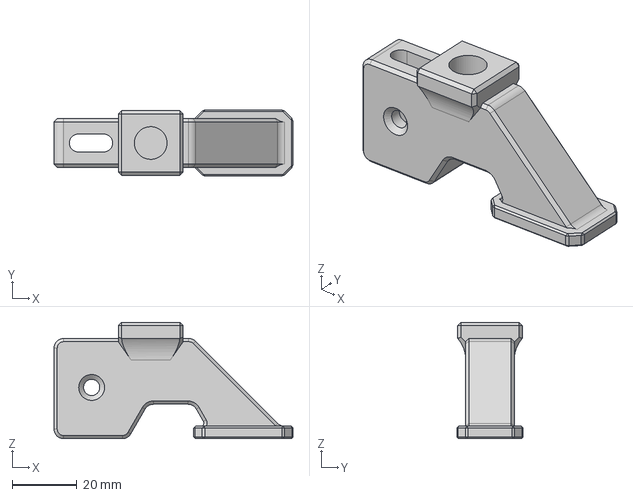
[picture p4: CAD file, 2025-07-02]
Open Task Light Express/Community-Made Alternatives/robocat-studios - Base for IRWIN QUICK-GRIP/Base for IRWIN QUICK-GRIP.step
73.9 x 20.5 x 36.0 mm

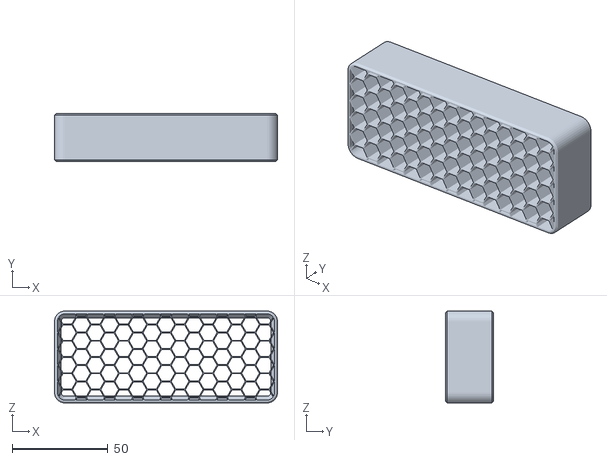
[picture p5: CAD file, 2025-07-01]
Open Task Light Express/Community-Made Alternatives/tobias -> led holder -> neewer tl96/neewer_tl96_grid.stl
116.5 x 25.0 x 48.0

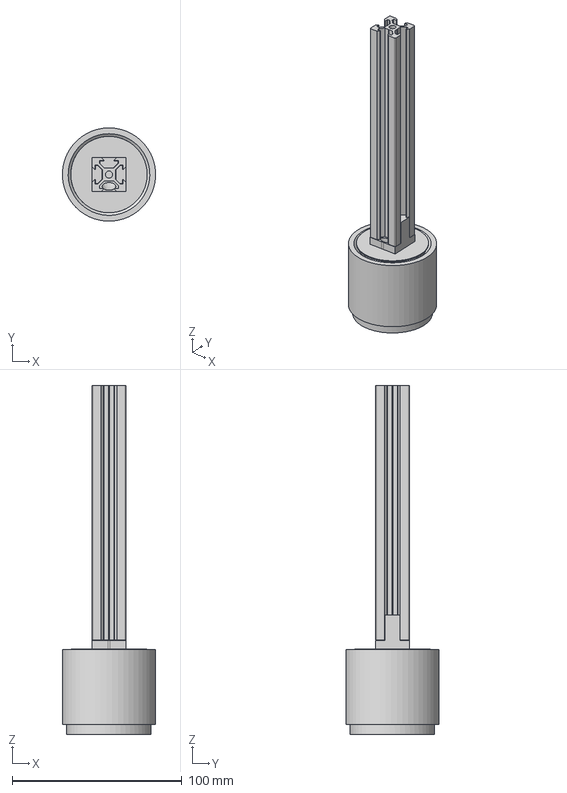
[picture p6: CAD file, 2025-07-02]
Open Task Light/Community-Made Alternatives/Tim - Base/Base.step
55.0 x 55.0 x 205.7 mm
Body_Kugel_einzeln (1) x 8
Body_Innenring (1)
Body_Aussenring (1)
20x20Rail
SlipRing
BoxUpper
BoxLower
Spacer
RailConnector

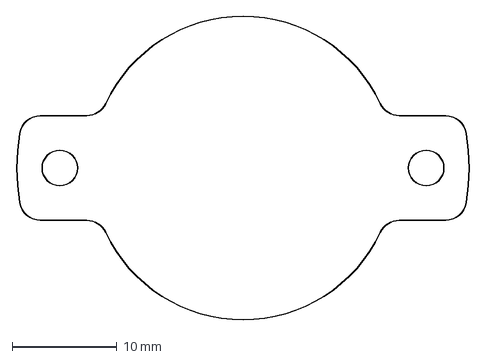
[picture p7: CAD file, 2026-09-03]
Open Task Light/Manufactured Parts/Aluminum Heat Pipe Top Plate/aluminum-heat-pipe-top-plate.dxf
43.4 x 29.0 mm

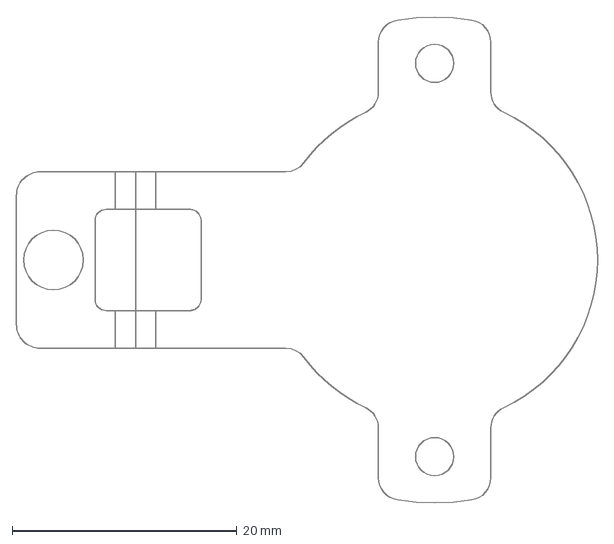
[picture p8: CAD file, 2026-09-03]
Open Task Light/Manufactured Parts/Copper LED Bracket/copper-led-bracket.dxf
51.7 x 43.4 mm

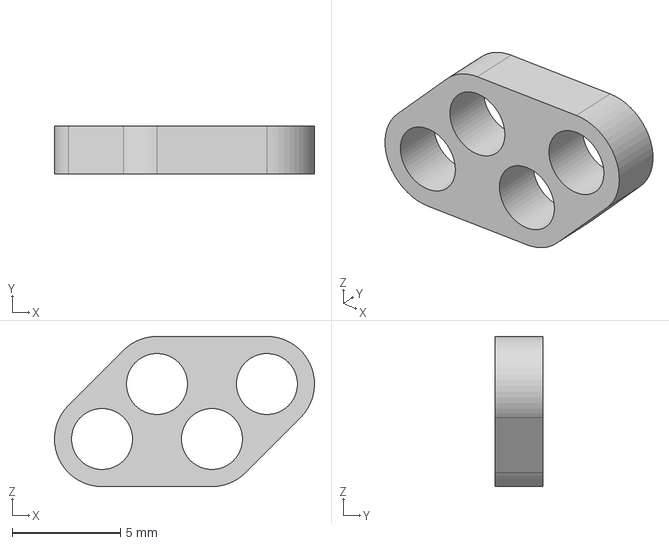
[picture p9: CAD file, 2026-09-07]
Open Task Light/Printed Parts/STEP/_Included in Kit/power-link-insulator_v1.0.step
12.0 x 2.21 x 6.94 mm

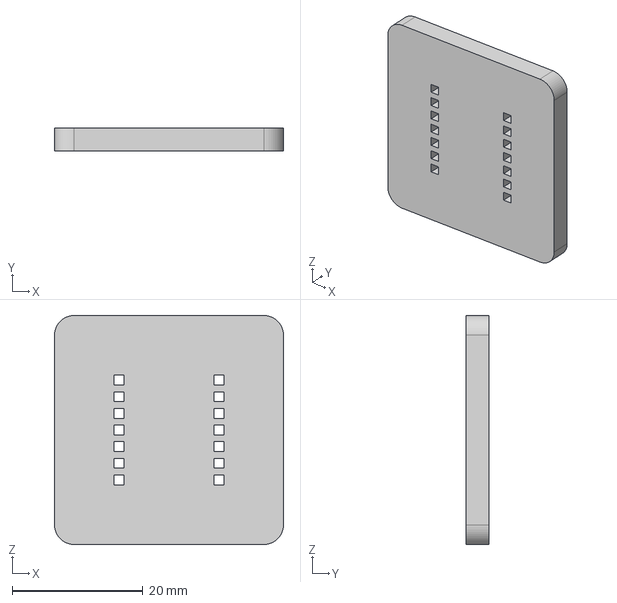
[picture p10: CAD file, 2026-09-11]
Open Task Light/Printed Parts/STEP/_Self-sourcing Tools/QT Py Header Trimmer.step
35.0 x 3.50 x 35.0 mm

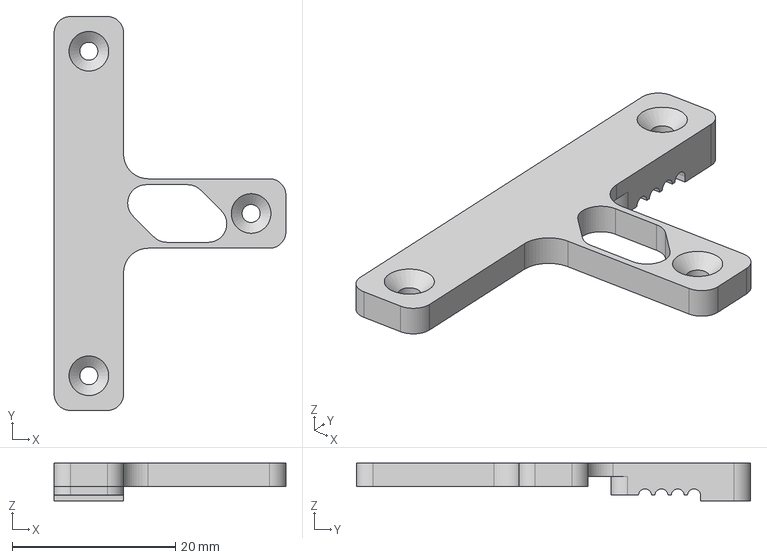
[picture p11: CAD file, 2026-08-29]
Open Task Light/Printed Parts/STEP/Carriage/carriage-clip_v1.0.step
28.4 x 48.2 x 4.61 mm

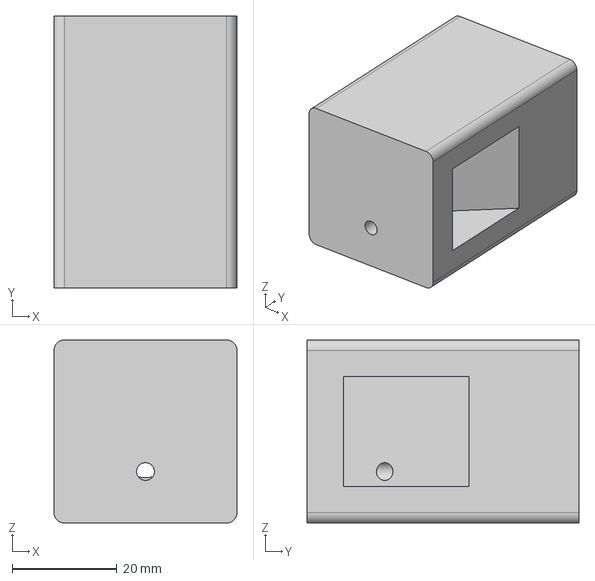
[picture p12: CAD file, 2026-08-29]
Open Task Light/Printed Parts/STEP/Clamping Base/clamping-base_v1.0.step
35.0 x 52.0 x 35.0 mm

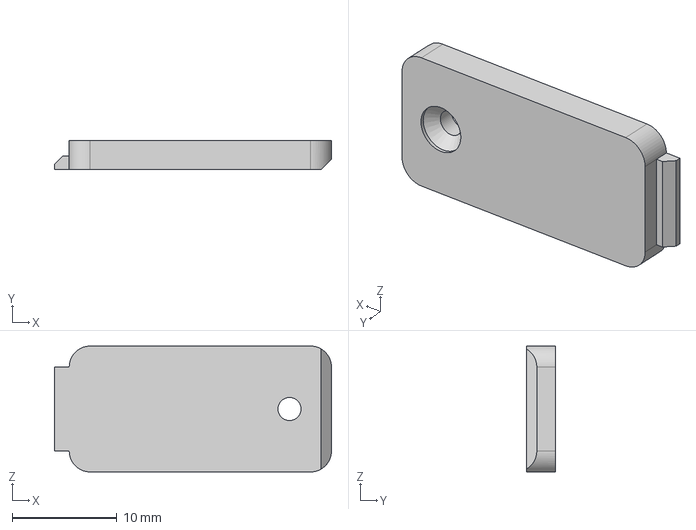
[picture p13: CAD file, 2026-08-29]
Open Task Light/Printed Parts/STEP/Counterweight/counterweight-lid-lead_v1.0.step
26.4 x 2.80 x 12.0 mm

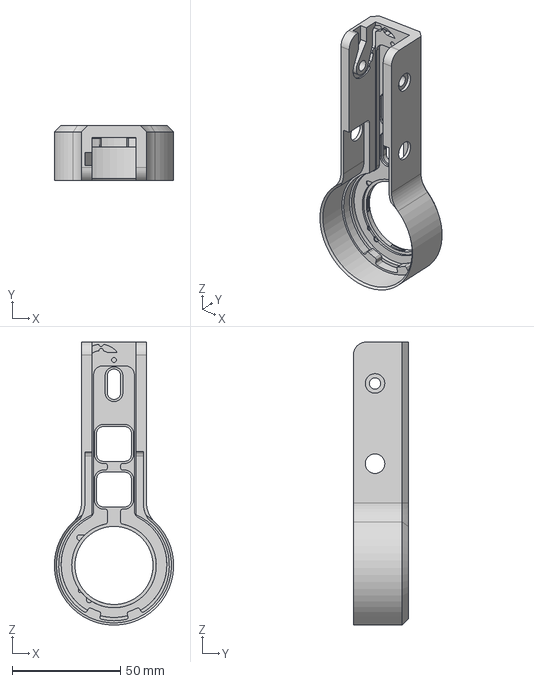
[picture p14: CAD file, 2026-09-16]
Open Task Light/Printed Parts/STEP/Electronics Housing/electronics-housing_v1.2.step
55.0 x 25.5 x 130.4 mm

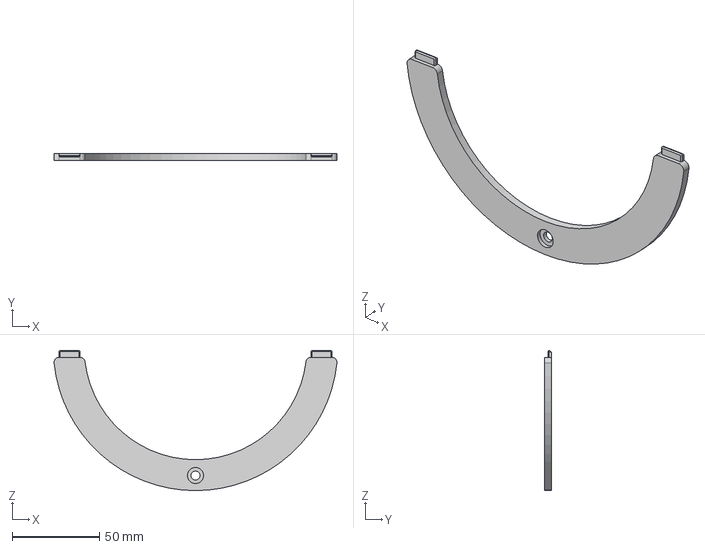
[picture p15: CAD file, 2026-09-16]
Open Task Light/Printed Parts/STEP/Freestanding Base/freestanding-base-outer-shell-lid_v1.1.step
161.9 x 3.90 x 80.2 mm

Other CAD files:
Open Task Light/Printed Parts/STEP/Power Tracks/power-track-support-alt-thinner(2.45)_v1.0.step
Open Task Light/Printed Parts/STEP/Rail Ends/pulley-mount_v1.0.step
Open Task Light/Printed Parts/STEP/Tools/hardware-fit-tester_v1.0.step
Open Task Light Express/Community-Made Alternatives/brukhabtu - LED Holder (LumeCube)/LEDHolderLumeCube.step
Archive/Open Task Light Express/Community-Made Alternatives/brukhabtu - LED Holder (LumeCube)/LEDHolderLumeCube.step
Archive/Open Task Light Express/Community-Made Alternatives/jfuchs - Gimbal/Extrusion bracket.stl
Archive/Open Task Light Express/Community-Made Alternatives/jfuchs - Gimbal/Inner ring.stl
Archive/Open Task Light Express/Community-Made Alternatives/robocat-studios - Base for IRWIN QUICK-GRIP/Base for IRWIN QUICK-GRIP.3mf
Archive/Open Task Light Express/Community-Made Alternatives/tobias -> led holder -> neewer tl96/neewer_holder.f3d
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

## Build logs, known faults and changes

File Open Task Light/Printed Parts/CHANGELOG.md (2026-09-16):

# Printed Model Changelog

Release notes for versioned Open Task Light STEP and STL models.

## 2026-09-16

### STL mesh refinement

**Repository-wide export-quality update**

Standardized all STL exports using Fusion's `High` mesh-refinement setting. This update does not change model versions or critical geometry.

### `electronics-housing` — v1.2

**Successor release**

Additional space for control board length

### `freestanding-base-bottom-shell-lid` — v1.1

**Successor release**

Improved clearance between lid and bottom shell (thanks @vurmshmutz)

### `freestanding-base-bracket-cover` — v1.1

**Successor release**

Fillet on bottom faces to improve fit when elephant's foot is present (thanks @vurmshmutz)

### `freestanding-base-outer-shell-lid` — v1.1

**Successor release**

Improved tab clearance

### `freestanding-base-outer-shell` — v1.1

**Successor release**

Replaced standalone cylinder lid screw receptacle with attached rib (thanks @_ianofearth). Improved lid tab clearance (thanks @vurmshmutz)

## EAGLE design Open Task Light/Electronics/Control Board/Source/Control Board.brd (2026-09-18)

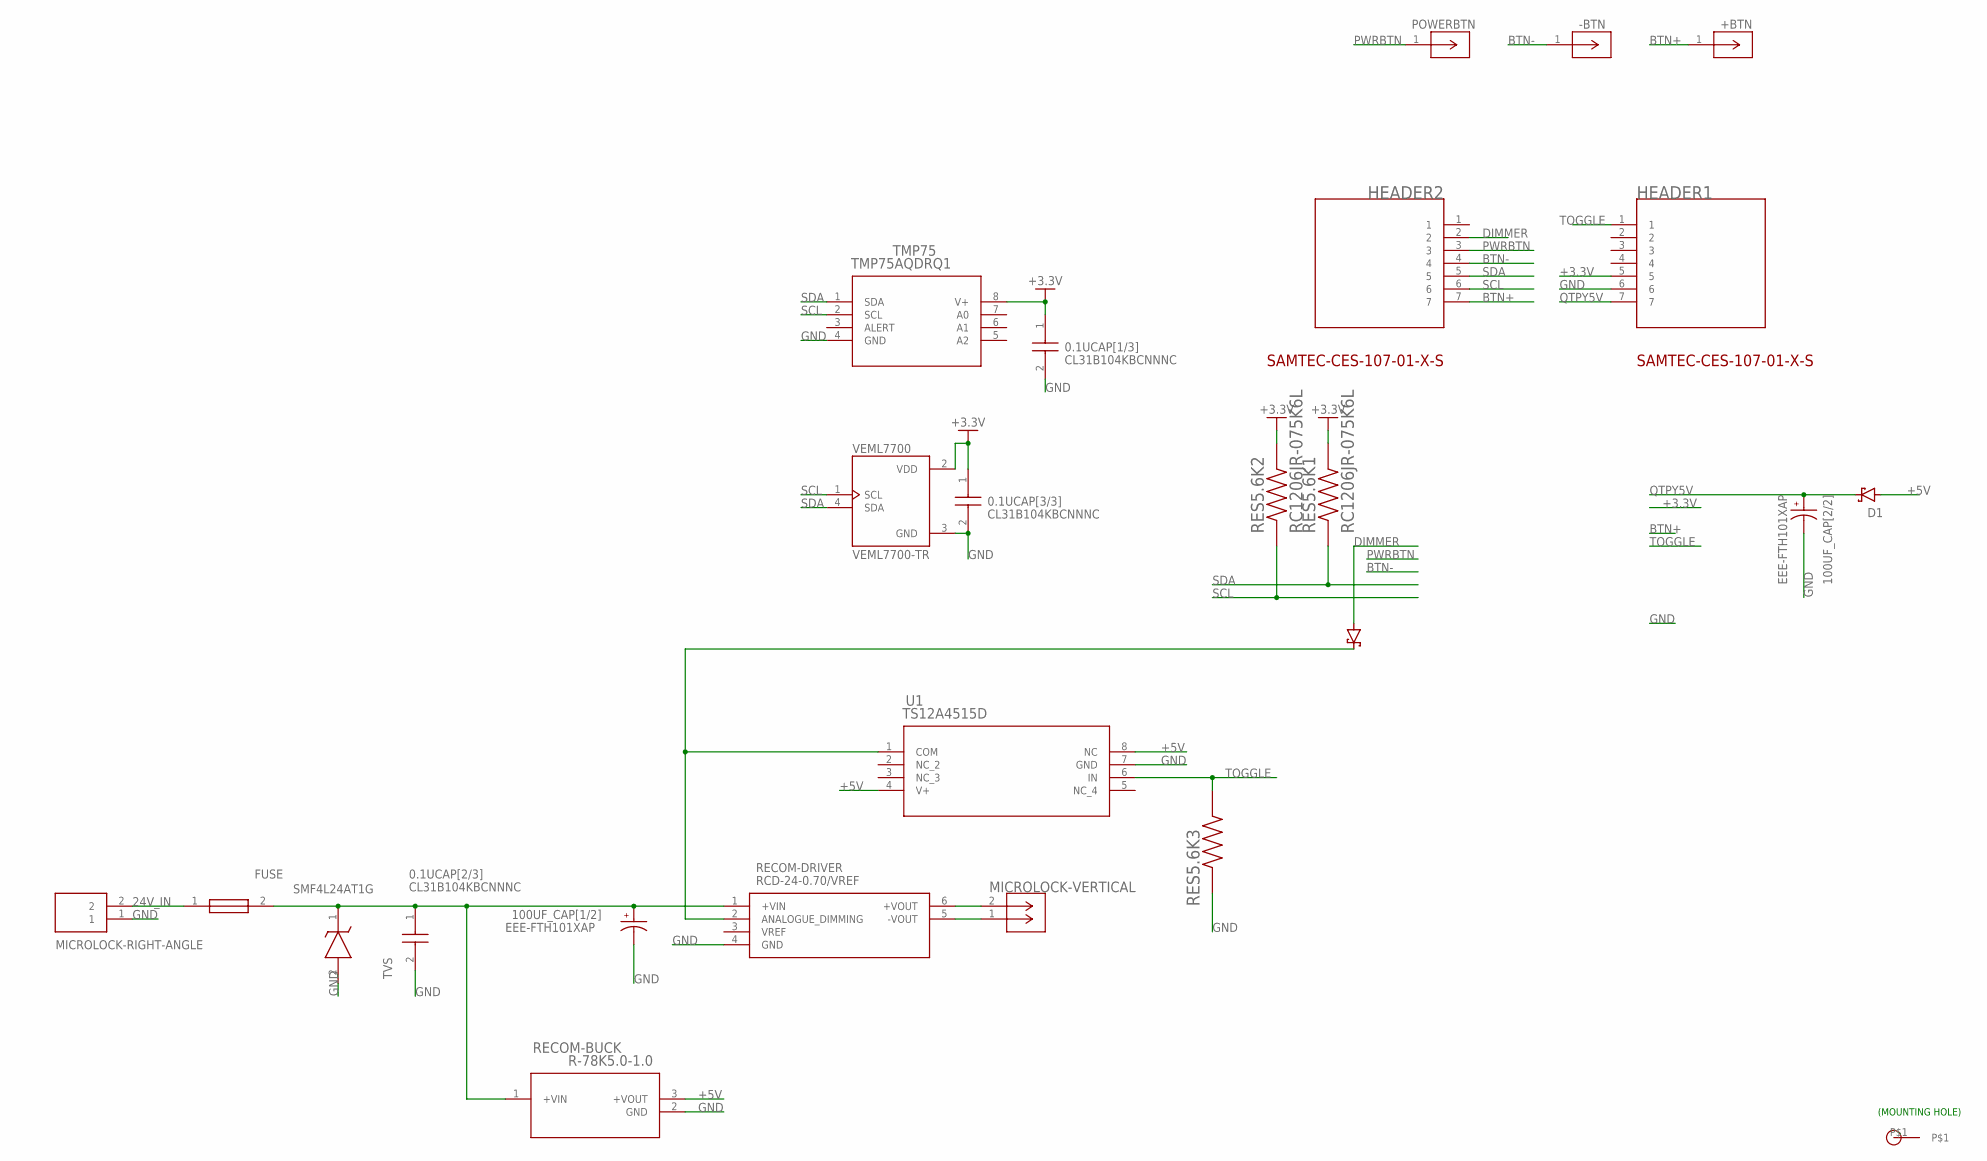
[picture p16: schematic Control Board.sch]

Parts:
0.1UCAP[1/3], 0.1UCAP[2/3], 0.1UCAP[3/3]: CL31B104KBCNNNC; CAPC3216X100N; MPN CL31B104KBCNNNC
100UF_CAP[1/2], 100UF_CAP[2/2]: EEE-FTH101XAP; CAP_EEEFTH101XAP; MPN EEE-FTH101XAP
+BTN: 807-22-001-10-001101; CONN_807-22-001-10-001101_MIM; MPN 807-22-001-10-001101
-BTN: 807-22-001-10-001101; CONN_807-22-001-10-001101_MIM; MPN 807-22-001-10-001101
D1, D3: PMEG4010EGWX; SOD-123; MPN PMEG4010EGWX
FUSE: SMD2016B100TF/33; MPN SMD2016B100TF/33
HEADER1, HEADER2: CES-107-01-G-S; SAMTEC-CES-107-01-X-S
MICROLOCK-RIGHT-ANGLE: 2200980271; MPN 2200980271
MICROLOCK-VERTICAL: 2200970271; CONN_2200970000-SD_02_MOL; MPN 2200970271
POWERBTN: 807-22-001-10-001101; CONN_807-22-001-10-001101_MIM; MPN 807-22-001-10-001101
RECOM-BUCK: R-78K5.0-1.0; R-78K5.0-1.0_RCP; MPN R-78K5.0-1.0
RECOM-DRIVER: RCD-24-0.70/VREF; RCD24030; MPN RCD-24-0.70/VREF
RES5.6K1, RES5.6K2, RES5.6K3: RC1206JR-075K6L; RESC3116X65N; MPN RC1206JR-075K6L
TMP75: TMP75AQDRQ1; D8_TEX; MPN TMP75AQDRQ1
TVS: SMF4L24AT1G; SODFL3619X98N
U1: TS12A4515D; D8-L; MPN TS12A4515D
U$2: 2.5MMPLATEDTHROUGHHOLE; 2.5MMPLATEDHOLE
VEML7700: VEML7700-TR; XDCR_VEML7700-TR; MPN VEML7700-TR

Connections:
24V_IN: FUSE.1, MICROLOCK-RIGHT-ANGLE.2
+3.3V: 0.1UCAP[1/3].1, 0.1UCAP[3/3].1, HEADER1.5, RES5.6K1.2, RES5.6K2.2, TMP75.8 (V+), VEML7700.2 (VDD)
+5V: D1.A, RECOM-BUCK.3 (+VOUT), U1.4 (V+), U1.8 (NC)
+24V: 0.1UCAP[2/3].1, 100UF_CAP[1/2].1, FUSE.2, RECOM-BUCK.1 (+VIN), RECOM-DRIVER.1 (+VIN), TVS.1 (K)
A0: D3.C, RECOM-DRIVER.2 (ANALOGUE_DIMMING), U1.1 (COM)
BTN+: +BTN.1, HEADER2.7
BTN-: -BTN.1, HEADER2.4
DIMMER: D3.A, HEADER2.2
GND: 0.1UCAP[1/3].2, 0.1UCAP[2/3].2, 0.1UCAP[3/3].2, 100UF_CAP[1/2].2, 100UF_CAP[2/2].2, HEADER1.6, MICROLOCK-RIGHT-ANGLE.1, RECOM-BUCK.2 (GND), RECOM-DRIVER.4 (GND), RES5.6K3.1, TMP75.4 (GND), TVS.2 (A), U1.7 (GND), VEML7700.3 (GND)
LED+: MICROLOCK-VERTICAL.2 (1), RECOM-DRIVER.6 (+VOUT)
LED-: MICROLOCK-VERTICAL.1 (2), RECOM-DRIVER.5 (-VOUT)
PWRBTN: HEADER2.3, POWERBTN.1
QTPY5V: 100UF_CAP[2/2].1, D1.C, HEADER1.7
SCL: HEADER2.6, RES5.6K2.1, TMP75.2 (SCL), VEML7700.1 (SCL)
SDA: HEADER2.5, RES5.6K1.1, TMP75.1 (SDA), VEML7700.4 (SDA)
TOGGLE: HEADER1.1, RES5.6K3.2, U1.6 (IN)

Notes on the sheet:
(MOUNTING HOLE)

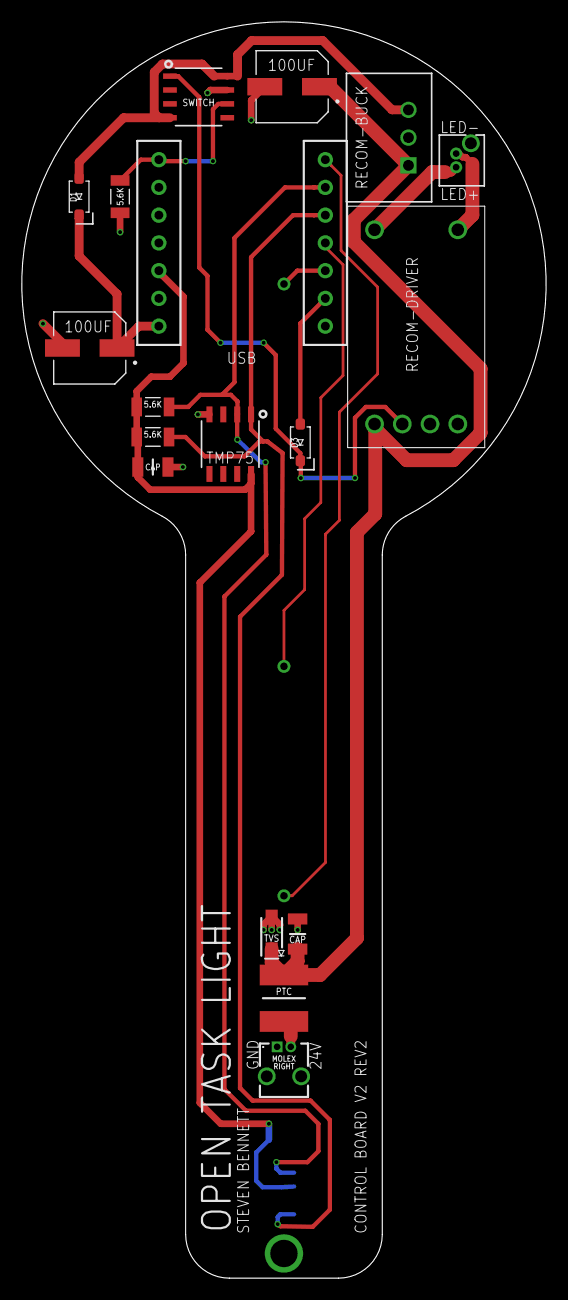
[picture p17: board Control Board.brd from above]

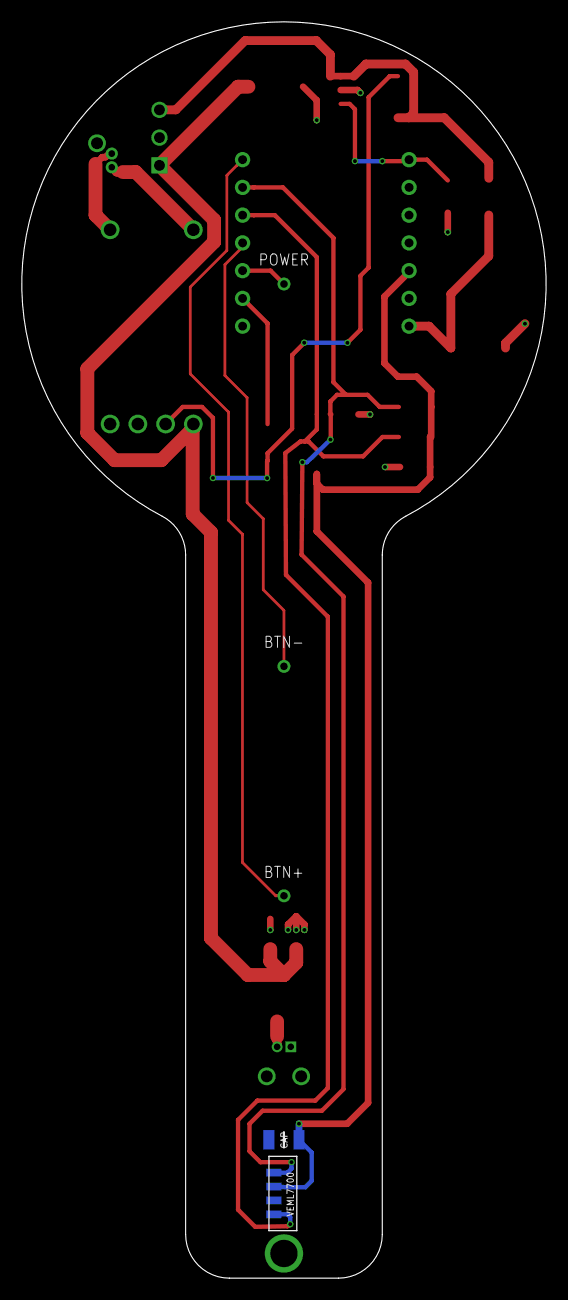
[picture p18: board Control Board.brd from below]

Board: 2 copper layers, 48.0 x 115.0 mm, 25 parts (5 on the bottom side), 16 nets.

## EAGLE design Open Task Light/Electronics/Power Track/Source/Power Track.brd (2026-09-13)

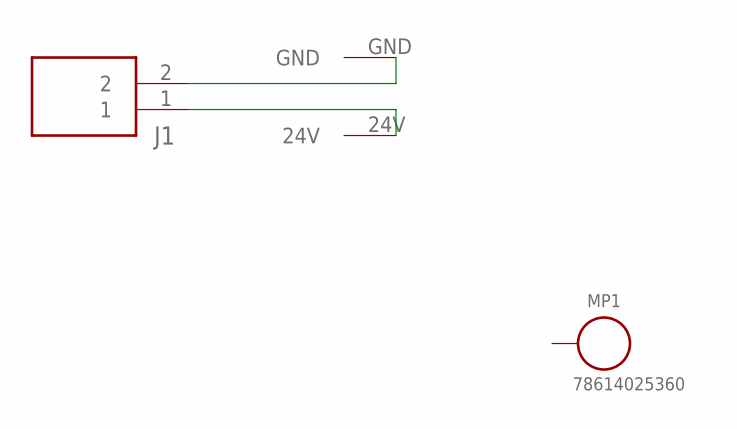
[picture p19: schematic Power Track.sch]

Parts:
CONTACT_PADS: POWERTRACKPAD; POWER-TRACK-PADS
J1: 2200980271
MP1: 78614025360; WE-SMSA_78614020360

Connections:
24V: CONTACT_PADS.24V, J1.1
GND: CONTACT_PADS.GND, J1.2

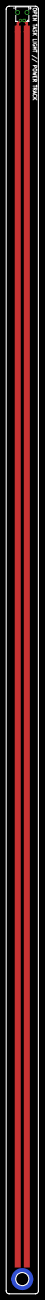
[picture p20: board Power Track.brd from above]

Board: 2 copper layers, 10.8 x 432.0 mm, 3 parts (1 on the bottom side), 2 nets.

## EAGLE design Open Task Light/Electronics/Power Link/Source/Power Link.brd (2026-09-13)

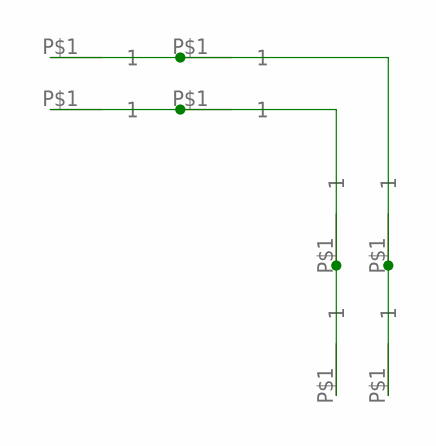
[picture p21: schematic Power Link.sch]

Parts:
PIN1, PIN2, PIN3, PIN4, PIN5, PIN6, PIN7, PIN8: 0945-0-15-20-09-14-11-0; MILL_MAX_0945_SMD

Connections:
unnamed: PIN1.P$1, PIN3.P$1, PIN5.P$1, PIN7.P$1
unnamed: PIN2.P$1, PIN4.P$1, PIN6.P$1, PIN8.P$1

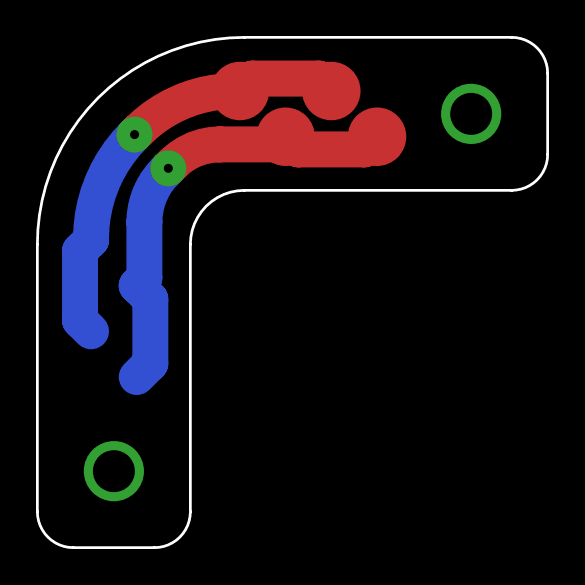
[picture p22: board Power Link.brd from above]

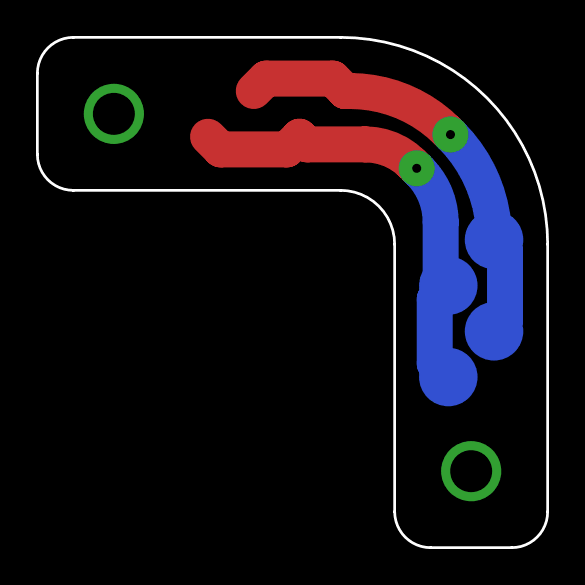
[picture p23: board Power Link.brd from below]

Board: 2 copper layers, 28.4 x 28.4 mm, 8 parts (4 on the bottom side), 2 nets.

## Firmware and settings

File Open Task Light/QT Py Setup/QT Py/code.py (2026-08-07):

import microcontroller
import time, board, busio, math
import digitalio
import adafruit_veml7700
from analogio import AnalogIn, AnalogOut
from touchio import TouchIn
from adafruit_debouncer import Debouncer
from barbudor_tmp75 import TMP75
import neopixel

# Onboard NeoPixel is on pin board.NEOPIXEL
pixel = neopixel.NeoPixel(board.NEOPIXEL, 1, brightness=0.3)  # adjust brightness 0.0–1.0

# this is just for basic boot testing you can comment it out or delete it or leave it.
pixel[0] = (0, 255, 0)  # Solid green (R, G, B)

##################
# INITIALIZATION #
##################
DEFAULT_MAX_16_BIT_VALUE = 65535 # this is currently equal to 0% brightness. I need to make sure this variable name makes sense and is used consistently.
max_16_bit_value = DEFAULT_MAX_16_BIT_VALUE
DEFAULT_POWER_OUTPUT = 100 # out of 100. used for global max power ceiling
POWER_OUTPUT_LIMIT = DEFAULT_POWER_OUTPUT  # used to adjust max output based on temperature
DAC_BRIGHTNESS_FLOOR = 55000# use this to ensure low brightness settings are visible/optimal. Also allows you to manual adjust the brightness of the lowest brightness level.
DAC_OFF_VALUE = DEFAULT_MAX_16_BIT_VALUE
BRIGHTNESS_RANGE = DAC_OFF_VALUE - DAC_BRIGHTNESS_FLOOR

# INITIALIZE THE RX PIN WHICH TURNS OFF THE IC SWITCH AFTER BOOT
switch_control = digitalio.DigitalInOut(board.RX)
switch_control.direction = digitalio.Direction.OUTPUT
switch_control.value = False

# INITIALIZE THE DAC OUT TO CONTROL THE LED DRIVER
dac_out = AnalogOut(board.A1)
# SET THE LED DRIVER OUTPUT OFF
dac_out.value = DAC_OFF_VALUE


# TURN THE IC SWITCH OFF, TURNING CONTROL OVER TO THE QTPY
switch_control.value = True


i2c = busio.I2C(board.SCL, board.SDA)

# INITIALIZE SENSORS
# LIGHT SENSOR (VEML7700)
light_sensor = adafruit_veml7700.VEML7700(i2c)
light_sensor.integration_time = 100

# TMP75 Temperature sensor
temp_sensor = TMP75(i2c)


# BUTTONS
power_button_raw = TouchIn(board.A2)
increase_button_raw = TouchIn(board.TX)
decrease_button_raw = TouchIn(board.A3)
power_button = Debouncer(lambda: power_button_raw.value)
increase_button = Debouncer(lambda: increase_button_raw.value)
decrease_button = Debouncer(lambda: decrease_button_raw.value)


############
# SETTINGS #
############
# LAMP SETUP
_power = False  # False means lamp is off by default (don't change this)
auto_brightness = False
temperature_scaling = True # Setting this false disables brightness scaling when temp sensor hits HIGH_TEMP. for safety the lamp will always turn off and stay off when it reaches MAX_TEMP
temperature_sample_rate = 3 #time in seconds to poll temperature sensor, not much benefit to reducing this (outside of testing)

# LED BRIGHTNESS CONFIG
# should probably update this so you can just declare one variable like `brightnesslevels = 4` and STEP, MIN_BRIGHTNESS, and MAX_BRIGHTNESS are calculated from that. This would allow you to easily go from 3 to 4 to 5 or even like 10 brightness levels without having to change a bunch of other variables. It might also break something even if you did all of that.
BRIGHTNESS_LEVELS = 4
STEP = 100 // BRIGHTNESS_LEVELS
MIN_BRIGHTNESS = STEP
MAX_BRIGHTNESS = STEP * (100 // STEP)
FADE_DURATION = 0.25
FADE_STEPS = 50
last_temp_check = 0

# AMBIENT LIGHT SENSOR CONFIG
LIGHT_SENSOR_MAX = 12000
LIGHT_SENSOR_MIN = 1

# TEMPERATURE SENSOR CONFIG
# these are conservative estimates based on PLA glass transition temperature of ~60c. can be bumped up a bit for PETG(75-80c) and bumped up quite a lot for polycarbonate 130c+ (check other component limits though...)
# internal temps can reach 56c if DEFAULT_POWER_OUTPUT is 100. haven't test at 90 or below.
HIGH_TEMP = 50
MAX_TEMP = 56

# CAPACITIVE TOUCH THRESHOLD, INCREASE IF TOO SENSITIVE
power_button_raw.threshold = 20000
increase_button_raw.threshold = 20000
decrease_button_raw.threshold = 20000


#############
# FUNCTIONS #
#############
# CLASSES
class Brightness:
    def __init__(self, percentage):
        self.flat_percentage = min(max(percentage, 0), 100)

    def as_driver_output(self):  # Converts from percentage to equivalent DAC output for the driver
        if self.flat_percentage == 0:
            return DAC_OFF_VALUE
        # Scale the brightness by the power output limit
        effective_percentage = (self.flat_percentage * POWER_OUTPUT_LIMIT) / 100
        normalized_brightness = effective_percentage / 100
        scaled_brightness = 1 - (normalized_brightness ** 2)
        dac_value = int(scaled_brightness * DAC_BRIGHTNESS_FLOOR)
        return dac_value

class AmbientBrightness:
    def __init__(self, sensor, min_value, max_value):
        self.sensor = sensor
        self.min_value = min_value
        self.max_value = max_value
        self.last_task_time = time.monotonic()

    def update(self): #limit frequency of value updates (hopefully allows lamp to wait for stable lighting conditions)
        if time.monotonic() - self.last_task_time >= 2:
            self.last_task_time = time.monotonic()
            return self.sensor.lux
        return None

    def get_brightness_lux(self):
        return self.sensor.lux


    def get_brightness_percentage(self): #converts the lux value to a scaled value then to a percentage to compare to user_brightness
        lux = self.sensor.lux
        shifted_lux = lux - self.min_value + 1  
        normalized_lux = shifted_lux / (self.max_value - self.min_value + 1)
        scaled_brightness = (math.log(normalized_lux * 9 + 1) / math.log(10)) * 100

        return min(max(scaled_brightness, 0), 100)


# SET INITIAL BRIGHTNESS
user_brightness = Brightness(STEP)
output_brightness = Brightness(0)
ambient_brightness = AmbientBrightness(light_sensor, LIGHT_SENSOR_MIN, LIGHT_SENSOR_MAX)


def get_temperature():
    # debugging
    print(f"Temperature: {temp_sensor.temperature_in_C}°C")

    return temp_sensor.temperature_in_C

def set_output_brightness(target_brightness, duration=FADE_DURATION):
    global output_brightness
    step_duration = duration / FADE_STEPS

    # manually set some end points if start or end value is "off" for smoother tranistions
    start_value = DAC_OFF_VALUE if output_brightness.flat_percentage == 0 else output_brightness.as_driver_output()
    end_value = DAC_OFF_VALUE if target_brightness.flat_percentage == 0 else target_brightness.as_driver_output()

    for step in range(FADE_STEPS + 1):
        fraction = step / FADE_STEPS
        current_value = int(start_value + (end_value - start_value) * fraction)
        dac_out.value = current_value
        time.sleep(step_duration)

    output_brightness = target_brightness

    # debugging
    print(f"Current brightness: {output_brightness.flat_percentage}% | DAC Output: {output_brightness.as_driver_output()}")
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

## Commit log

2025-07-02 Carriage refinement
    Removed unnecessary chamfer on m5 screw holes (should help keep screws straighter)
    [Carriage.step, Carriage.stl]
2025-07-02 Removing some DIYson references in subdirectories
    DIYson -> Open Task Light
    DIYson Express -> Open Task Light Express
    [Added Parts.csv, Base for IRWIN QUICK-GRIP.3mf, Base for IRWIN QUICK-GRIP.step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]
2025-07-02 Carriage countersink depth fix
    Fixed M5 screw countersink depth to work with both 25mm and 27mm M5 screws. Will likely switch to 27mm only in the future.
    [Carriage.step, Carriage.stl]
2025-07-02 Fixed file export
    [Carriage.step]
2025-07-04 Clean-up
    Removed some cosmetic fillets added for blender
    [Carriage.step, Carriage.stl]
2026-08-07 1.0 STLs
    - Added OTL v1.0 STLs
    - Removed outdated models and info from past versions
    [Base.f3d, Base.step, Base.stl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]
2026-08-09 Create carriage-body_v1.1.stl
    Corrected screw head counterbore (was 9mm, now 9.2mm)
    [carriage-body_v1.1.stl]
2026-08-11 Freestanding base bottom shell update to 1.1
    Increased hole size for latest plug
    [freestanding-base-bottom-shell_v1.0.stl, freestanding-base-bottom-shell_v1.1.stl]
2026-08-11 Removed v1.0 carriage
    [carriage-body_v1.0.stl]
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2026-08-12 models: refine carriage body
    [carriage-body_v1.1.stl]
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2026-08-29 Added STEP files
    [carriage-body_v1.1.step, carriage-clip_v1.0.step, clamping-base-power-plug-clip_v1.0.step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]
2026-08-30 Added power link insulator STL
    [power-link-insulator_v1.0.stl]
2026-08-31 Add generated public BOM files
    [bom-clamping.csv, bom-freestanding.csv]
2026-08-31 Move public BOM files to stable paths
    [OTL-BOM-Clamping.csv, OTL-BOM-Freestanding.csv]
2026-09-02 Add Power Track PCB files
    [Power Track.brd, Power Track.sch, power-track-bom.csv]
2026-09-03 Add manufactured metal part files
    [aluminum-heat-pipe-top-plate.dxf, copper-led-bracket.dxf]
2026-09-04 Add rail length to public BOMs
    [OTL-BOM-Clamping.csv, OTL-BOM-Freestanding.csv]
2026-09-04 Archive Open Task Light Express
    [Base for IRWIN QUICK-GRIP.3mf, Base for IRWIN QUICK-GRIP.step, Extrusion bracket.stl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]
2026-09-04 Add sourcing criticality to public BOMs
    [OTL-BOM-Clamping.csv, OTL-BOM-Freestanding.csv]
2026-09-06 Update public BOM exports
    [OTL-BOM-Clamping.csv, OTL-BOM-Freestanding.csv]
2026-09-07 Add Power Link manufacturing files
    [PnP_Power Link Omniball_back.csv, PnP_Power Link Omniball_front.csv, Power Link.brd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]
2026-09-07 Update BOM processing requirements
    [OTL-BOM-Clamping.csv, OTL-BOM-Freestanding.csv]
2026-09-07 Standardize millimeter spacing in BOMs
    [OTL-BOM-Clamping.csv, OTL-BOM-Freestanding.csv]
2026-09-07 Updated 3d models
    Power link insulator: re-link after PCB export updates and update orientation (STEP and STL)
    Counterweight flex tab: update orientation
    [counterweight-flex-tab_v1.0.stl, power-link-insulator_v1.0.step, power-link-insulator_v1.0.stl]
2026-09-07 Added hardware fit tester model
    STL and STEP
    [Hardware Fit Tester.step, Hardware Fit Tester.stl]
2026-09-07 Added hardware fit tester models
    [Hardware Fit Tester.stl, Hardware Fit Tester_v1.0.step, Hardware Fit Tester_v1.0.stl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]
2026-09-07 fixed hardware fit tester filename
    [hardware-fit-tester_v1.0.step, hardware-fit-tester_v1.0.stl]
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2026-09-08 BoM Updates
    Added opentasklight.com store links where applicable
    [OTL-BOM-Clamping.csv, OTL-BOM-Freestanding.csv]
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2026-09-08 BoM Category updates
    Changed category labels from singular to plural
    [OTL-BOM-Clamping.csv, OTL-BOM-Freestanding.csv]
2026-09-08 Refresh generated BOM CSVs
    [OTL-BOM-Clamping.csv, OTL-BOM-Freestanding.csv]
2026-09-08 Electronics housing update
    V1.1 adds angled face to the bottom of the control board retention tabs which makes it easier to insert the control board, easier to remove support material, and slightly easier to print the tabs ove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
    Thanks to @thecritters and @_ianofearth in Discord for the help.
    [electronics-housing_v1.0.step, electronics-housing_v1.0.stl, electronics-housing_v1.1.step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]
2026-09-09 BOM update
    Remove "source critical" status from LED holder
    [OTL-BOM-Clamping.csv, OTL-BOM-Freestanding.csv]
2026-09-11 Self-sourcing tools directory
    Added a directory of tools to help people who are making their kits from scratch:
    - Heat pipe clamp
    - qt py header trimmer
    [Heat Pipe Clamp.step, Heat Pipe Clamp.stl, QT Py Header Trimmer.step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]
2026-09-11 Model origin fixes
    Fixed all model origins so they're oriented correctly on the build plate when brought into the slicer
    [carriage-body_v1.1.stl, carriage-clip_v1.0.stl, clamping-base-power-plug-clip_v1.0.stl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]
2026-09-11 BoM sourcing note
    Added sourcing warning to the heat pipe
    [OTL-BOM-Clamping.csv, OTL-BOM-Freestanding.csv]
2026-09-11 LED bracket source
    Added opentasklight.com as a sourcing option for LED brackets
    [OTL-BOM-Clamping.csv, OTL-BOM-Freestanding.csv]
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2026-09-11 Bom source otl.com
    Added otl.com as a source for some bom parts
    [OTL-BOM-Clamping.csv, OTL-BOM-Freestanding.csv]
2026-09-13 Control board PCB files + standardization
    [Control Board.brd, Control Board.sch, PnP_Control Board_back.csv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]
2026-09-13 BOM updates
    Added control board guide page links to boms
    [OTL-BOM-Clamping.csv, OTL-BOM-Freestanding.csv]
2026-09-15 Added PCB shop links to BOM
    [OTL-BOM-Clamping.csv, OTL-BOM-Freestanding.csv]
2026-09-16 Model improvements + changelog
    - Model printability improvements to freestanding base and electronics housing. Thanks to @vurmshmutz and @_ianofearth in the Discord for their detailed feedback.
    - Re-exported all STLs with Fusion "high" refinement setting (some were using medium setting)
    [carriage-body_v1.1.stl, carriage-clip_v1.0.stl, clamping-base-power-plug-clip_v1.0.stl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]
2026-09-17 Update OTL-BOM-Clamping.csv
    Added source criticality note for spacer + bushing combo
    [OTL-BOM-Clamping.csv]
2026-09-18 Control board gerber bottom layer fix (#60)
    Added bottom copper layer to Gerbers which was excluded from Fusion export
    Clean up top silkscreen to remove big `HEADER` labels
    [Control Board.brd]
2026-10-13 Fixed hole diameters for M3 tap
    Both holes in aluminum-heat-pipe-top-plate-M3tap.dxf are now R1.25 (Ø2.5 mm, the M3×0.5 tap drill size), still at (±17.5, −28). Only the hole diameters changed; the outline is identical to the original.

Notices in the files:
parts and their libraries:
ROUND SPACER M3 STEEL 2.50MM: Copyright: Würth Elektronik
